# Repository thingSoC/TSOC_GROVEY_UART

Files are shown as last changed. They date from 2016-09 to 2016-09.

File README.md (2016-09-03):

# TSOC_GROVEY_UART

The thingSoC GROVEY_UART Base board incorporates a Cypress CY7C65215 Dual Channel USB Bridge, that supports UART, I2C, SPI, and JTAG interfaces in a thingSoC format.

The thingSoC GROVEY_UART Base board has two USB bridge channels, which can be programmed to be either UART, I2C, SPI, JTAG, or Capacitance Sensing (buttons/sliders) Human Input devices.

USB Bridge One (Port 1) and USB Bridge Two (Port 2) are both connected to Grove System compatible connectors, and USB Bridge One (Port 1) is also connected to the thingSoC standard UART channel.

Port1 can be used to program a target microprocessor, at the same time Port2 is used for another purpose (i.e. debug channel, USB to RS-485 bridge, etc).  

It's like having two (2) FTDI adapters in One!

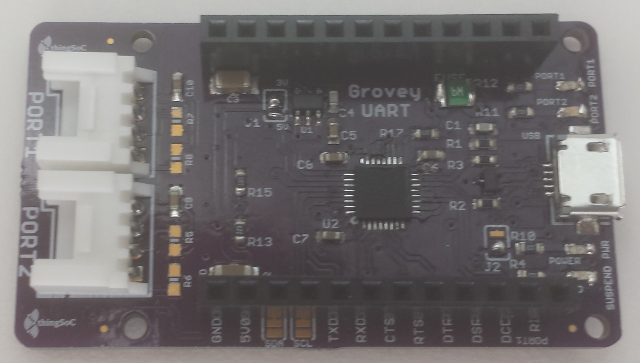
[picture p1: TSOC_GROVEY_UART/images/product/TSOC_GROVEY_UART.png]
thingSoC TSOC_GROVEY_UART
[ 
TSOC_GROVEY_UART](https://github.com/thingSoC/TSOC_GROVEY_UART)

---------------------------------------
## Use it as a Programming Dongle

---------------------------------------
## Use it as a Protocol Adapter

---------------------------------------
## TSOC_GROVEY_UART Model Images

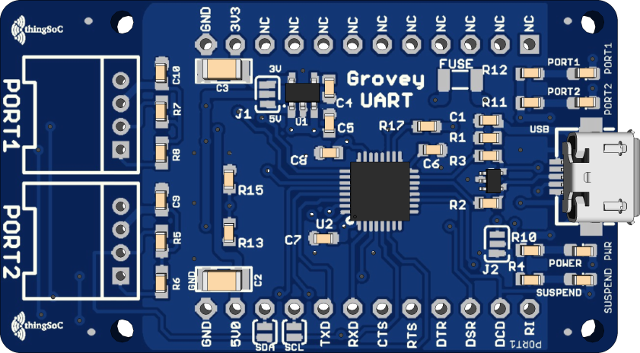
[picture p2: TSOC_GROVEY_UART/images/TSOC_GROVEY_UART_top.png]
thingSoC TSOC_GROVEY_UART
[ 
TSOC_GROVEY_UART](https://github.com/thingSoC/TSOC_GROVEY_UART)

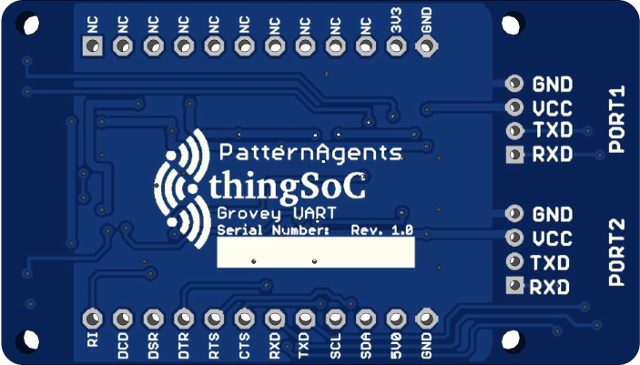
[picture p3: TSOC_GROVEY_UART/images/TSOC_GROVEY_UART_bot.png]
thingSoC TSOC_GROVEY_UART
[ 
TSOC_GROVEY_UART](https://github.com/thingSoC/TSOC_GROVEY_UART)

---------------------------------------

## TSOC_GROVEY_UART Status <a name="TSOC_GROVEY_UART_status"/>

Revision 1.0 - 09/02/2016

---------------------------------------

## TSOC_GROVEY_UART Documentation Index <a name="TSOC_GROVEY_UART_documentation_index"/>

[TSOC_GROVEY_UART Project](https://github.com/thingSoC/TSOC_GROVEY_UART/)

[TSOC_GROVEY_UART Hardware](https://github.com/thingSoC/TSOC_GROVEY_UART/tree/master/TSOC_GROVEY_UART/hardware)

---------------------------------------

## thingSoC Documentation Index <a name="thingSoC_documentation_index"/>

[thingSoC Organization Website](http://thingSoC.github.io)

[thingSoC FAQ - Frequently Asked Questions](http://thingsoc.github.io/support/faq.html)

---------------------------------------

[thingSoC 
*thingSoC*](http://thingsoc.github.io)

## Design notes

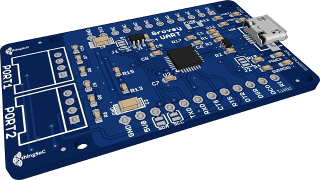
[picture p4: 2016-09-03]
TSOC_GROVEY_UART/images/TSOC_GROVEY_UART_model.png

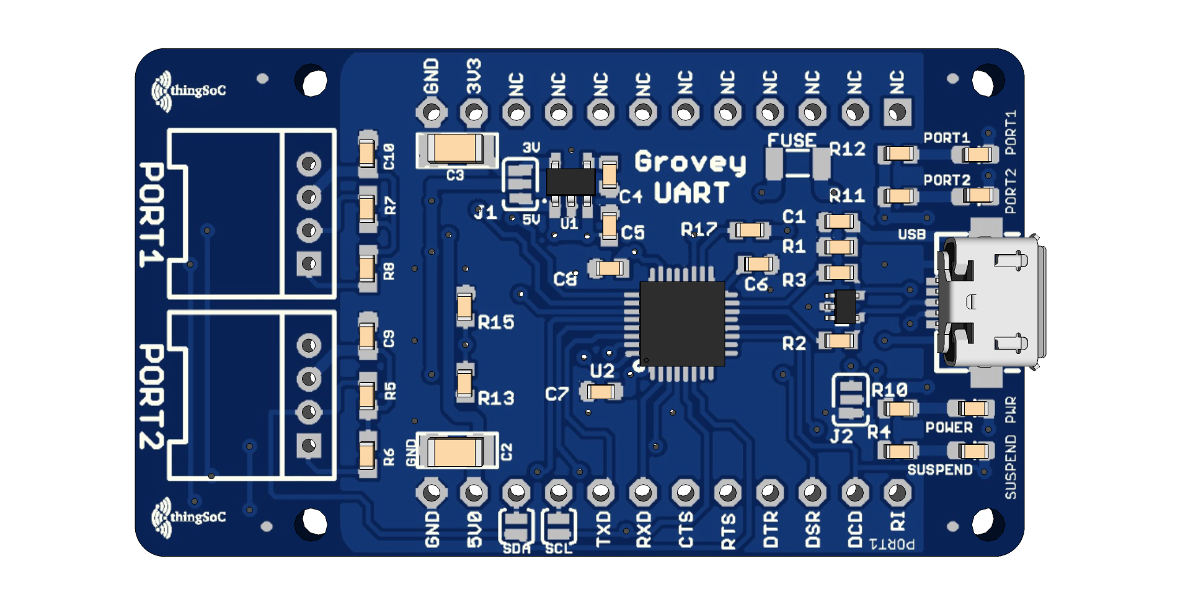
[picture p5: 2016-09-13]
TSOC_GROVEY_UART/images/TSOC_GROVEY_UART.png

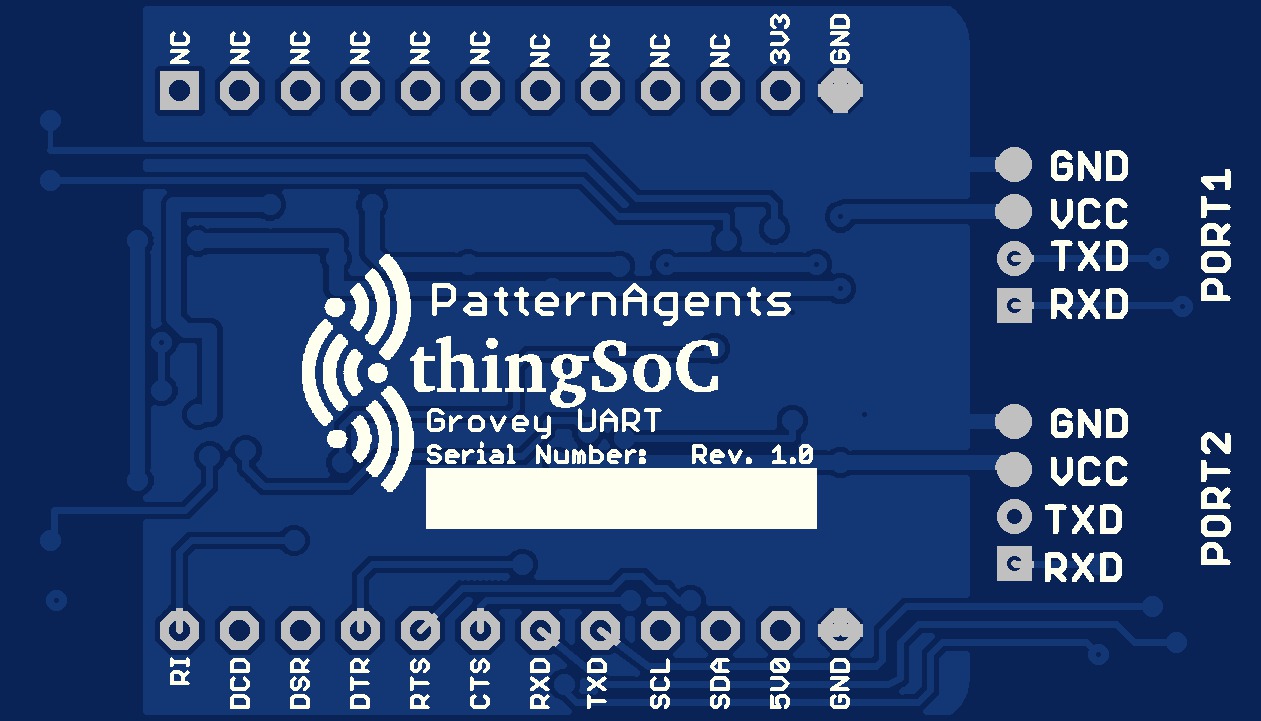
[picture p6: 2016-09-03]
TSOC_GROVEY_UART/eagleUp/eagleUp_TSOC_GROVEY_UART_board_bottom.jpg

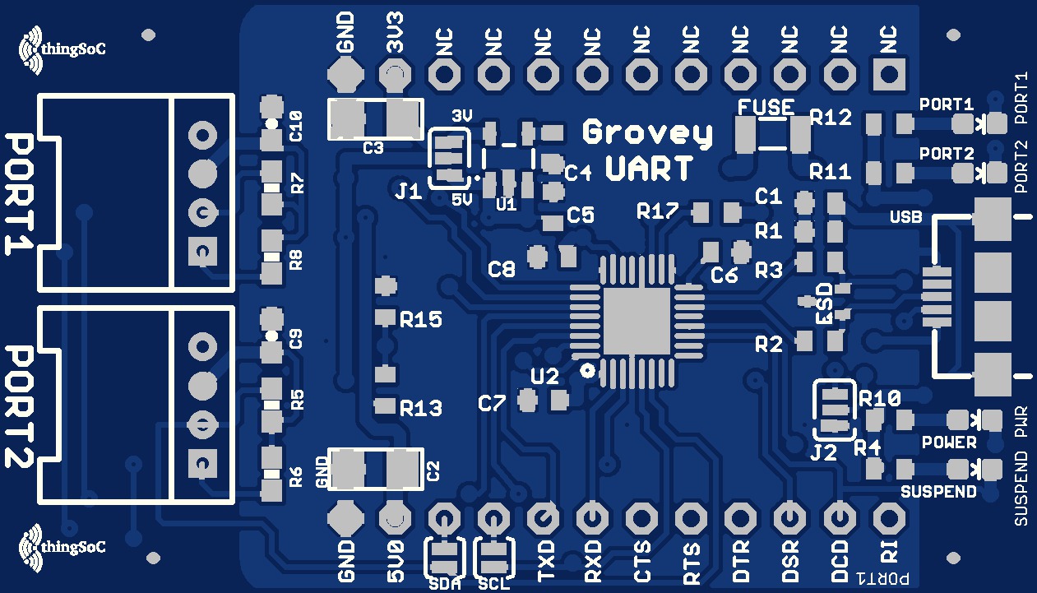
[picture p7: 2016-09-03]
TSOC_GROVEY_UART/eagleUp/eagleUp_TSOC_GROVEY_UART_board_top.jpg

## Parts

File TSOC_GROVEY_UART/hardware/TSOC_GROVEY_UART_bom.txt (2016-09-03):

Partlist exported from /data/customers/PatternAgents/eagle/TSOC_Modules/TSOC_GROVEY_UART/TSOC_GROVEY_UART/TSOC_GROVEY_UART.sch at 8/25/16 1:26 PM

Qty Value              Device                          Package                  Parts                  Description                                                                                                                                                                               
2                      JMP-2-NO                        JMP-2-NO                 SCL, SDA               Two Terminal Jumper - Normally Open                                                                                                                                                       
3   0.1uF              CAP-0603                        EIA-0603                 C5, C7, C8             Ceramic Capacitor SMD                                                                                                                                                                     
2   0.1uF              CAP0603-CAP                     0603-CAP                 C9, C10                Capacitor                                                                                                                                                                                 
1   1.0uF              CAP-0603                        EIA-0603                 C6                     Ceramic Capacitor SMD                                                                                                                                                                     
2   10K                RESISTOR-0603                   EIA-0603                 R15, R17                                                                                                                                                                                                         
4   1K                 RESISTOR-0603                   EIA-0603                 R4, R10, R11, R12                                                                                                                                                                                                
1   1M                 RESISTOR-0603                   EIA-0603                 R1                                                                                                                                                                                                               
2   22                 RESISTOR-0603                   EIA-0603                 R2, R3                                                                                                                                                                                                           
1   22K                RESISTOR-0603                   EIA-0603                 R13                                                                                                                                                                                                              
2   22uF               CAP-1206                        EIA-1206                 C2, C3                 Ceramic Capacitor SMD                                                                                                                                                                     
2   470pF              CAP-0603                        EIA-0603                 C1, C4                 Ceramic Capacitor SMD                                                                                                                                                                     
2   4P-2.0-90D         GROVE-CONNECTOR-DIP-90D(4P-2.0) HW4-2.0-90D              UART1, UART2           320110034                                                                                                                                                                                 
1   500mA-PTC          PTCSMD                          PTC-1206                 FUSE                   Resettable Fuse PTC                                                                                                                                                                       
1   BLUE               LED0603                         LED-0603                 PORT2                  LEDs                                                                                                                                                                                      
1   CY7C65215-32-PROTO CY7C65215-32-PROTO              QFN32-PROTO              U2                     Cypress EZ-USB ® CY7C65215-32QFN DUAL CHANNEL USB TO UART/SPI/IC Bridge                                                                                                                   
4   DNP                RESISTOR0603-RES                0603-RES                 R5, R6, R7, R8         Resistor                                                                                                                                                                                  
4   FIDUCIALUFIDUCIAL  FIDUCIALUFIDUCIAL               MICRO-FIDUCIAL           FID1, FID2, FID3, FID4 Fiducial Alignment Points                                                                                                                                                                 
1   GRN                LED0603                         LED-0603                 POWER                  LEDs                                                                                                                                                                                      
2   JMP-3-1_2          JMP-3-1_2                       JMP-3-1_2                J1, J2                 Three Terminal Jumper - 1 & 2 Connected                                                                                                                                                   
1   MIC5219 3.3V       V_REG_MIC52193.3V               SOT23-5                  U1                     V_REG MIC5219                                                                                                                                                                             
1   RED                LED0603                         LED-0603                 SUSPEND                LEDs                                                                                                                                                                                      
1   SP1001-02JTG       SP1001-02JTG                    SC70-3                   ESD                    Littelfuse SP1001-02JTG TVS Diode Array 8pf 15kV Source: 
1   USB_AB             USB_AB                          USB-AB-MICRO-SMD         USB                    This is a USB AB connector that is compatible with USB OTG.                                                                            
1   YELLOW             LED0603                         LED-0603                 PORT1                  LEDs

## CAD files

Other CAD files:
TSOC_GROVEY_UART/eagleUp/TSOC_GROVEY_UART.skp

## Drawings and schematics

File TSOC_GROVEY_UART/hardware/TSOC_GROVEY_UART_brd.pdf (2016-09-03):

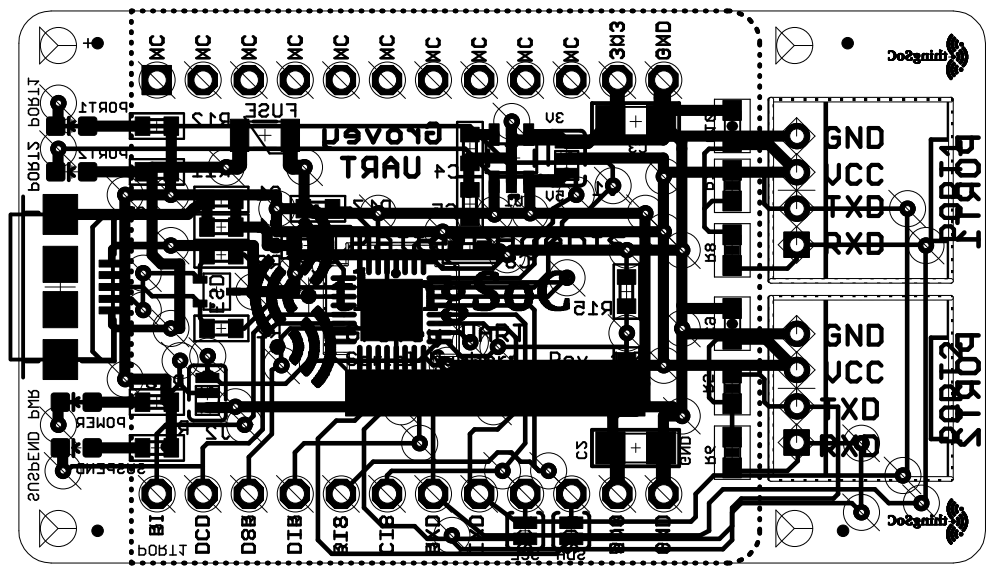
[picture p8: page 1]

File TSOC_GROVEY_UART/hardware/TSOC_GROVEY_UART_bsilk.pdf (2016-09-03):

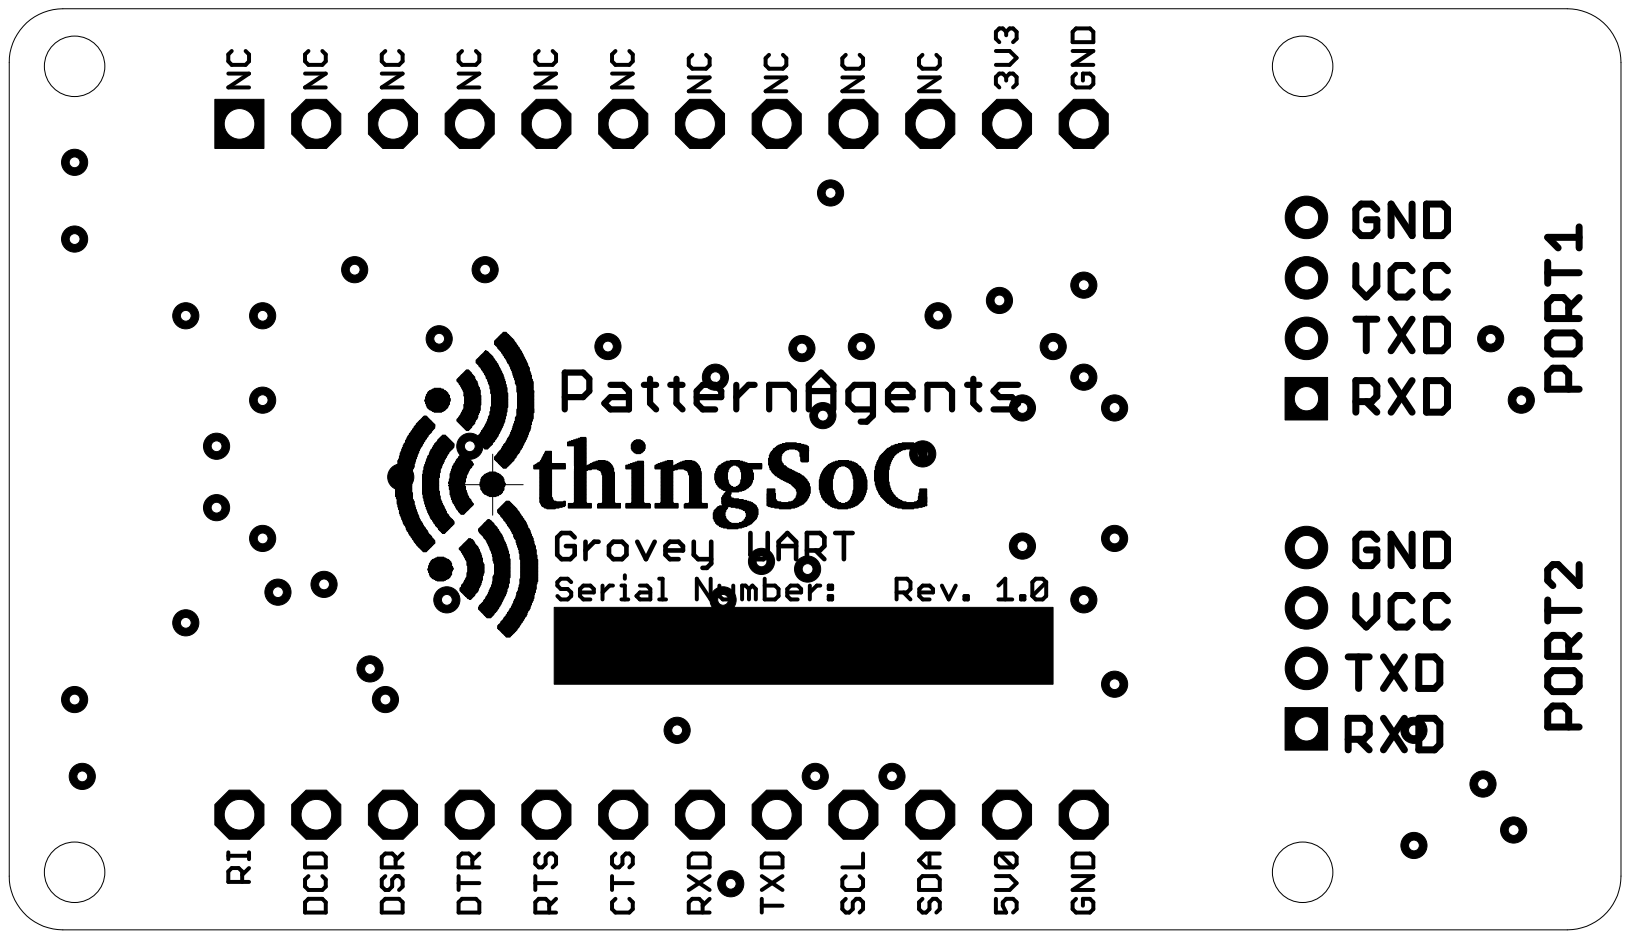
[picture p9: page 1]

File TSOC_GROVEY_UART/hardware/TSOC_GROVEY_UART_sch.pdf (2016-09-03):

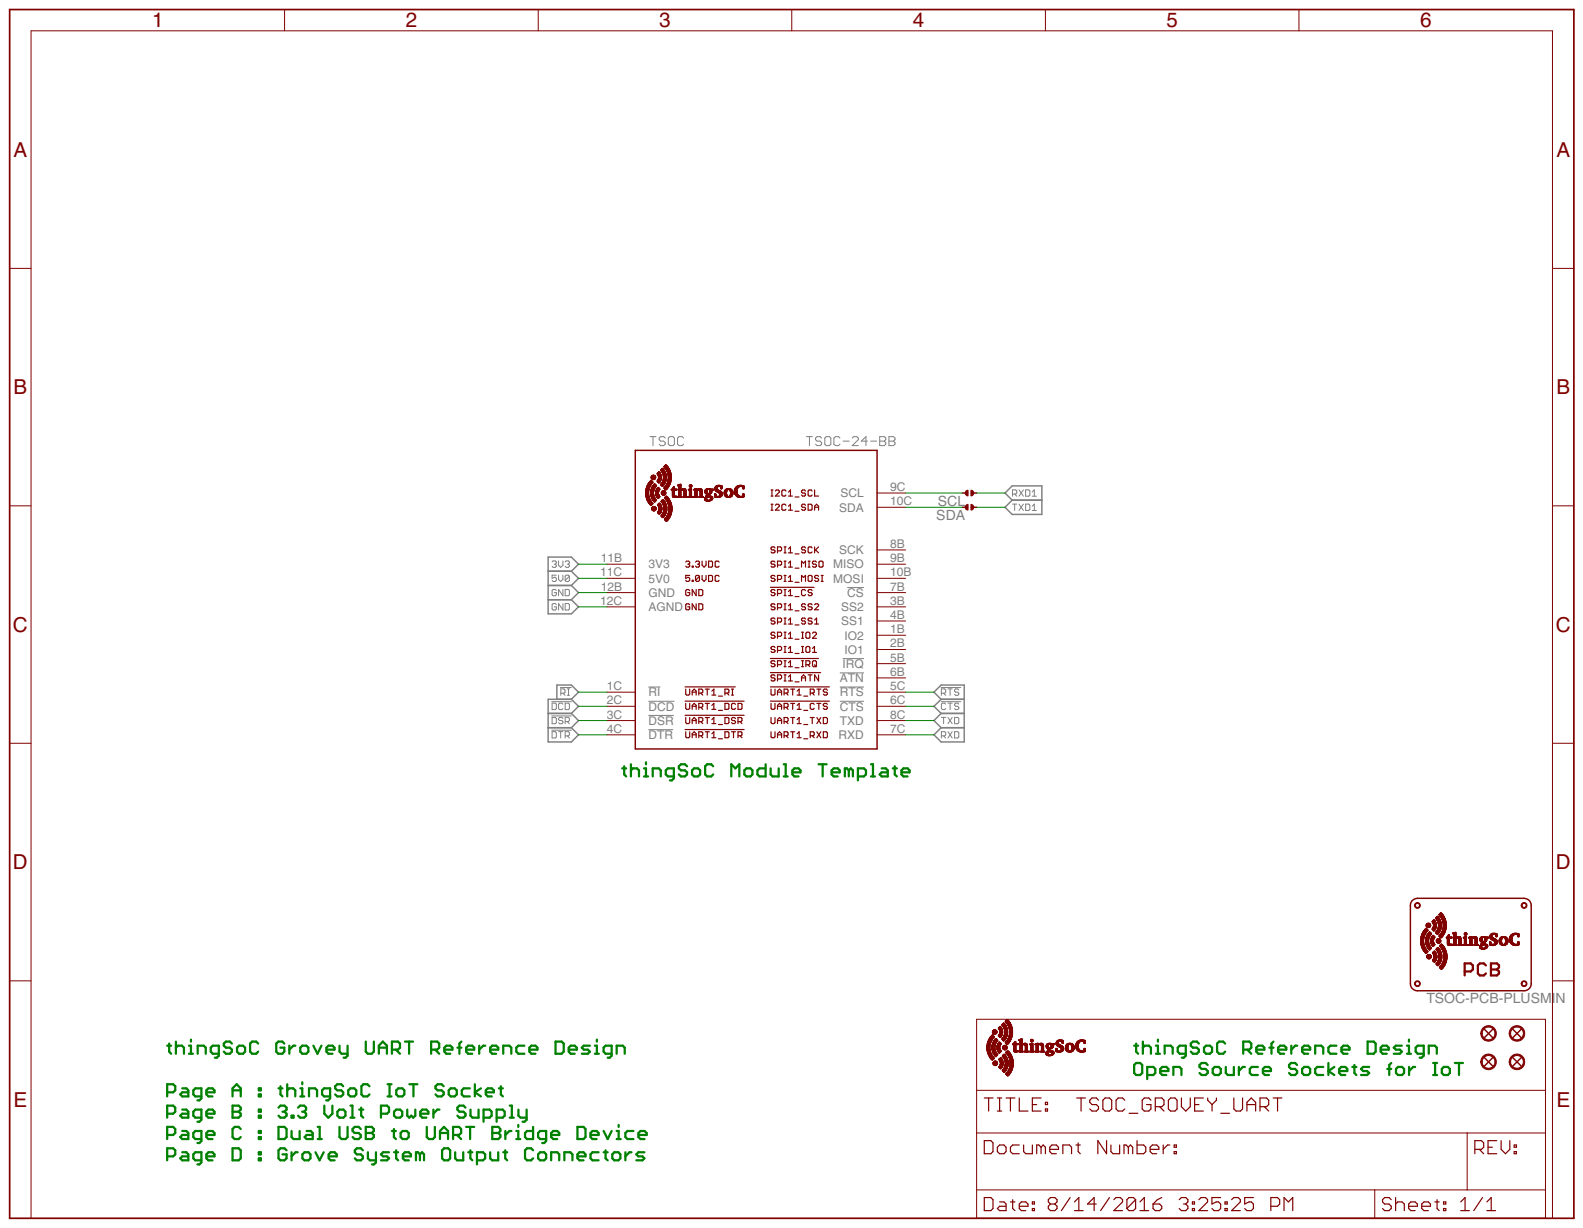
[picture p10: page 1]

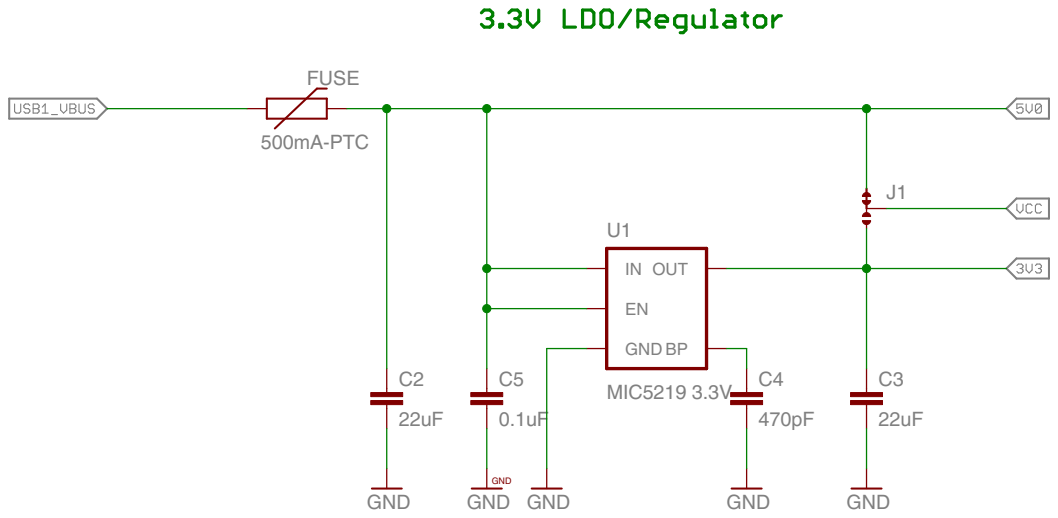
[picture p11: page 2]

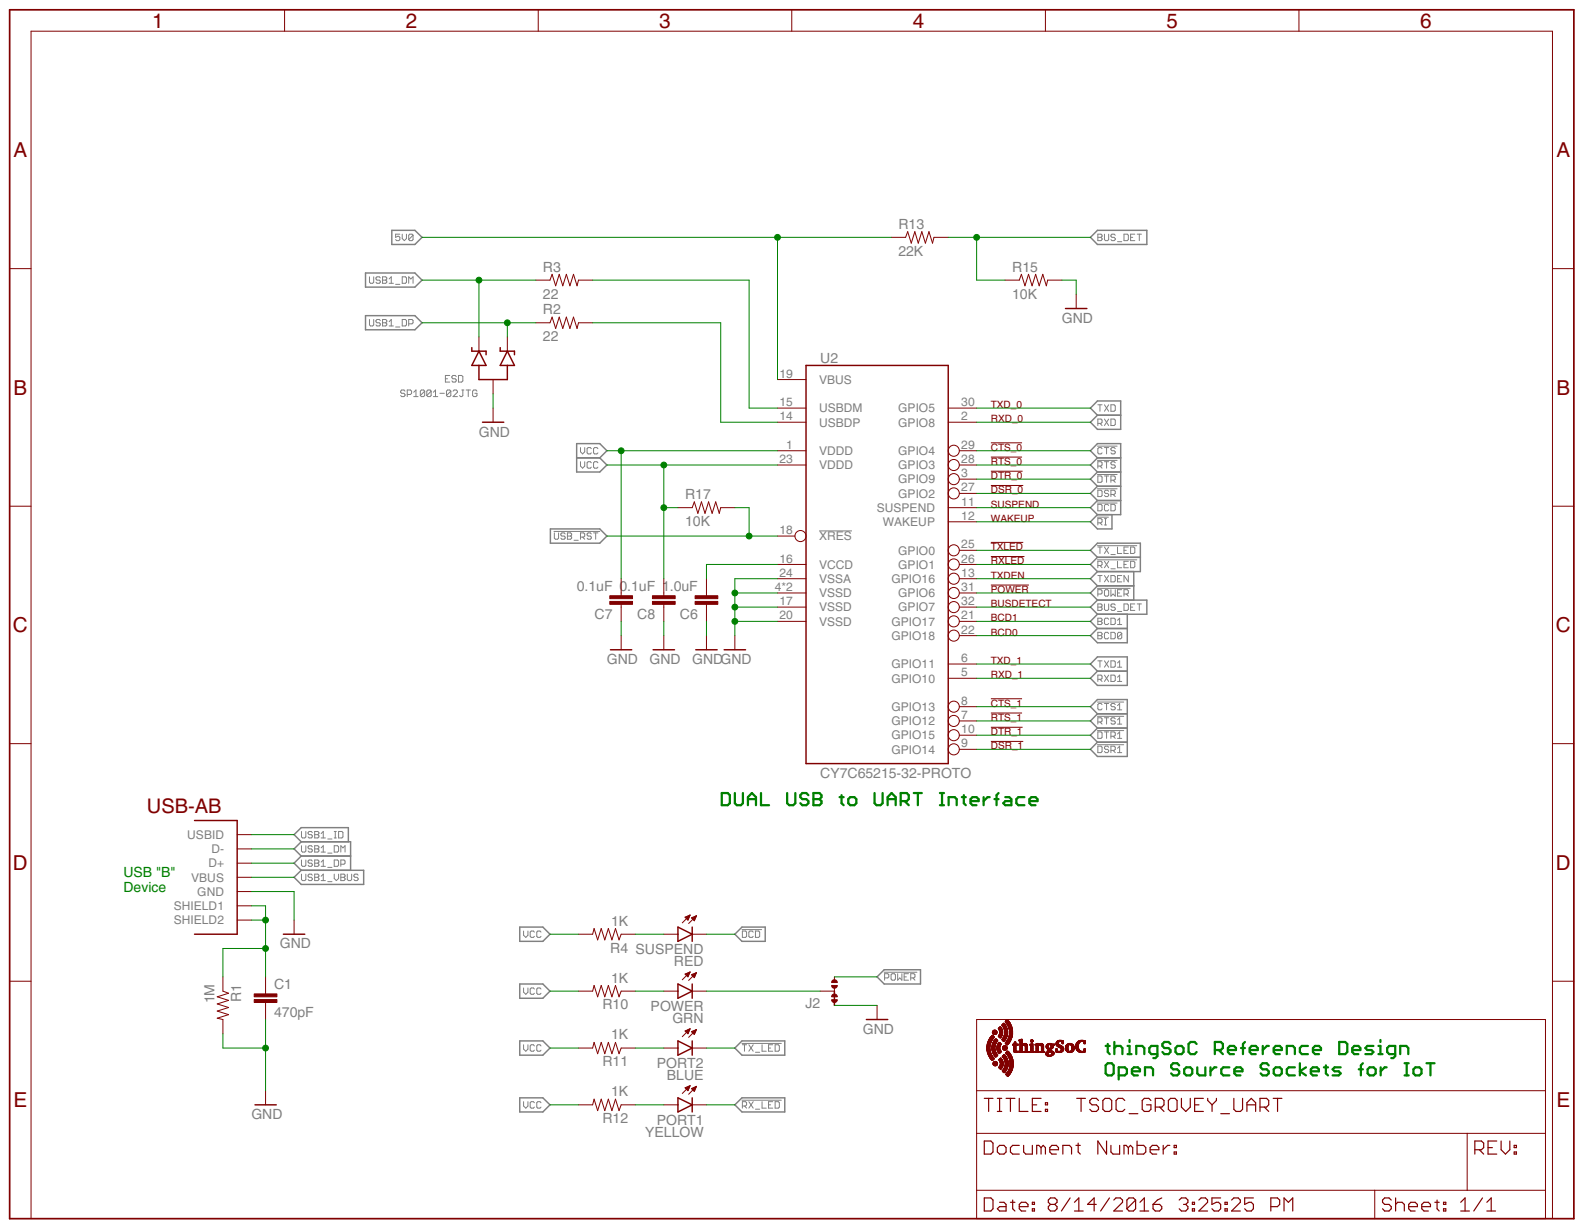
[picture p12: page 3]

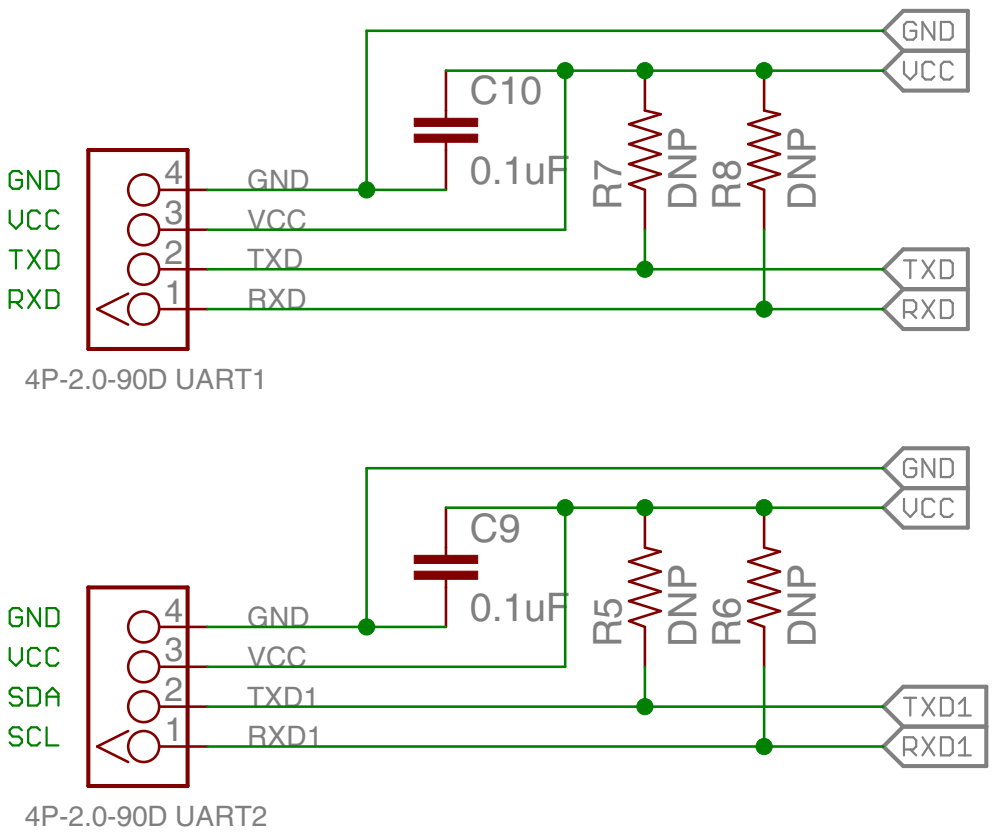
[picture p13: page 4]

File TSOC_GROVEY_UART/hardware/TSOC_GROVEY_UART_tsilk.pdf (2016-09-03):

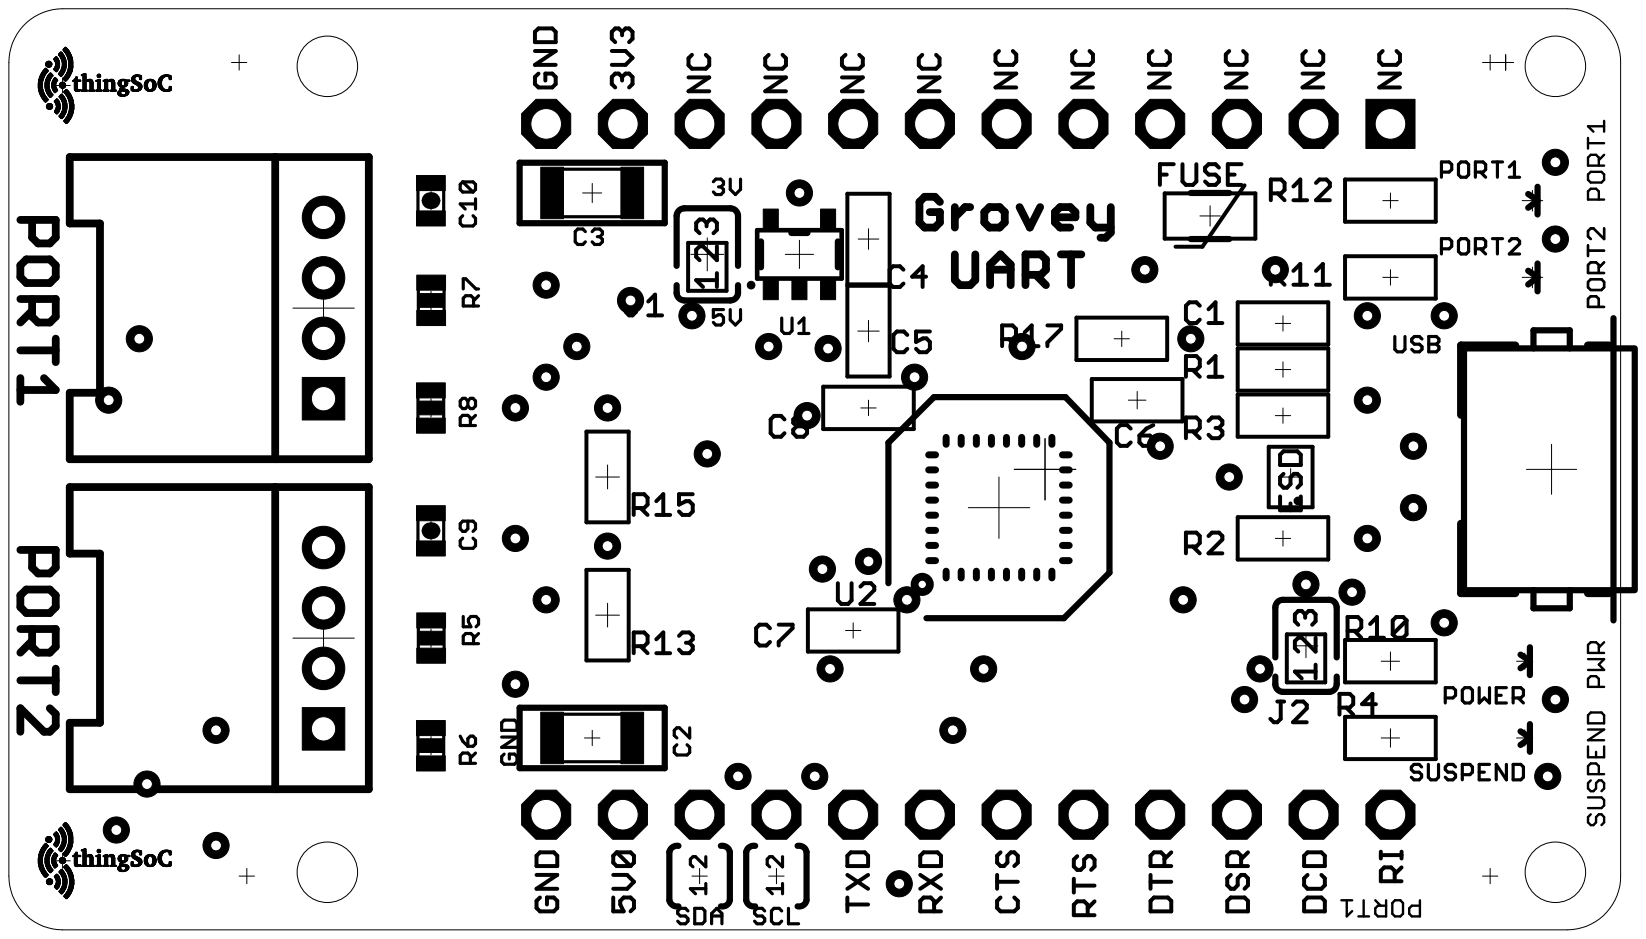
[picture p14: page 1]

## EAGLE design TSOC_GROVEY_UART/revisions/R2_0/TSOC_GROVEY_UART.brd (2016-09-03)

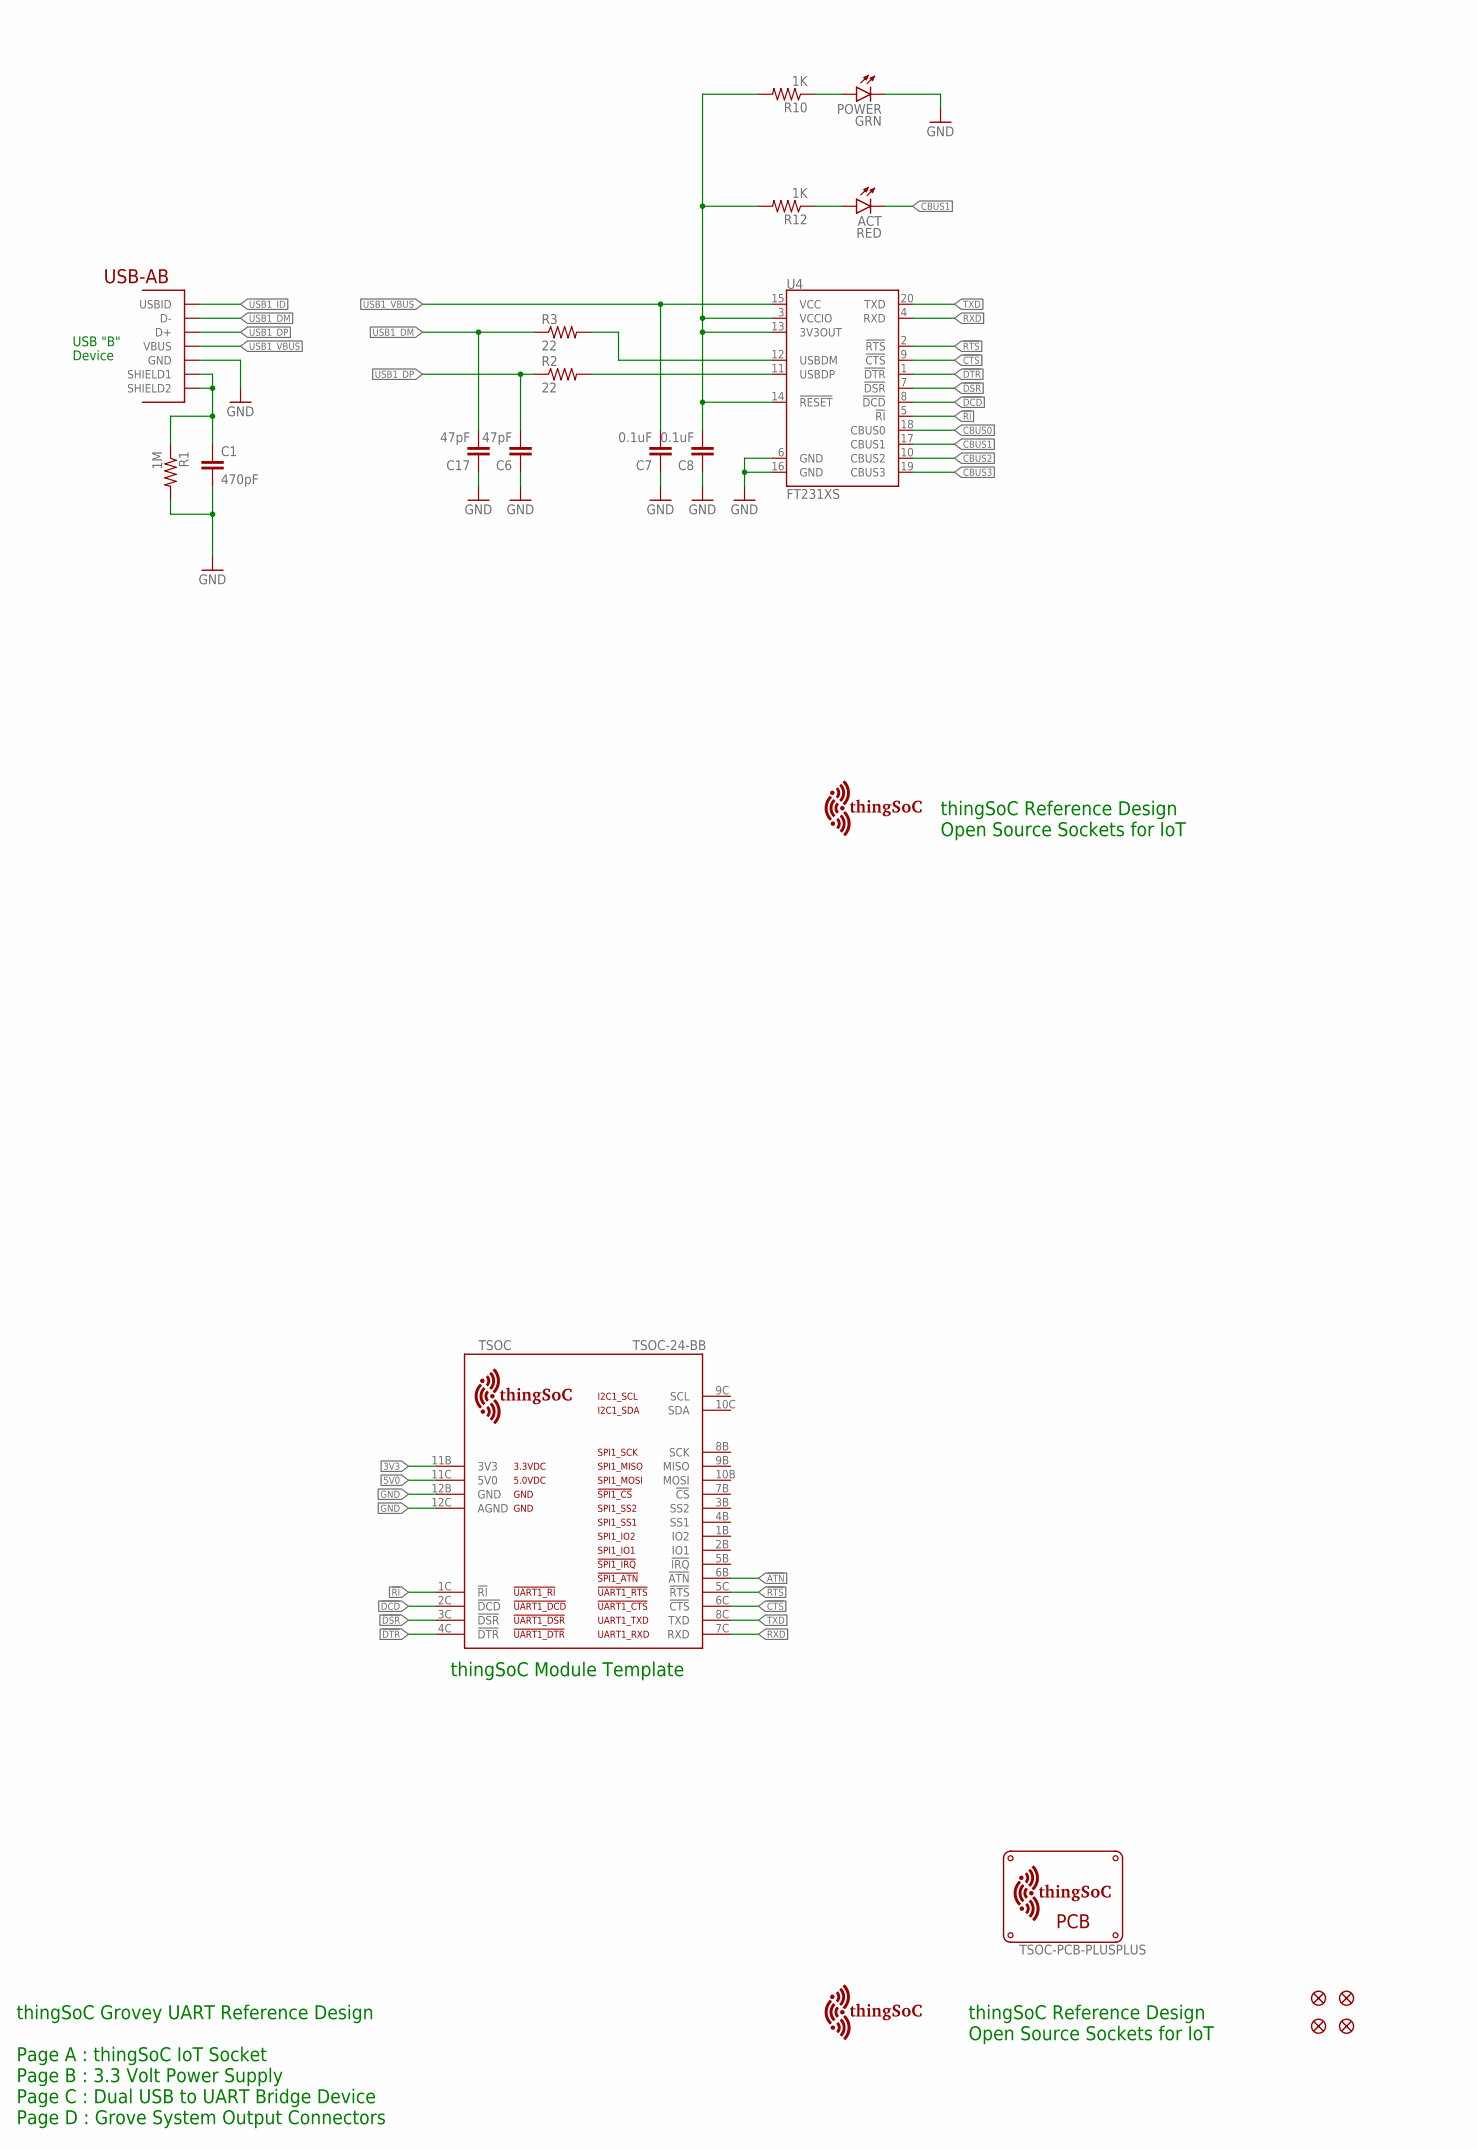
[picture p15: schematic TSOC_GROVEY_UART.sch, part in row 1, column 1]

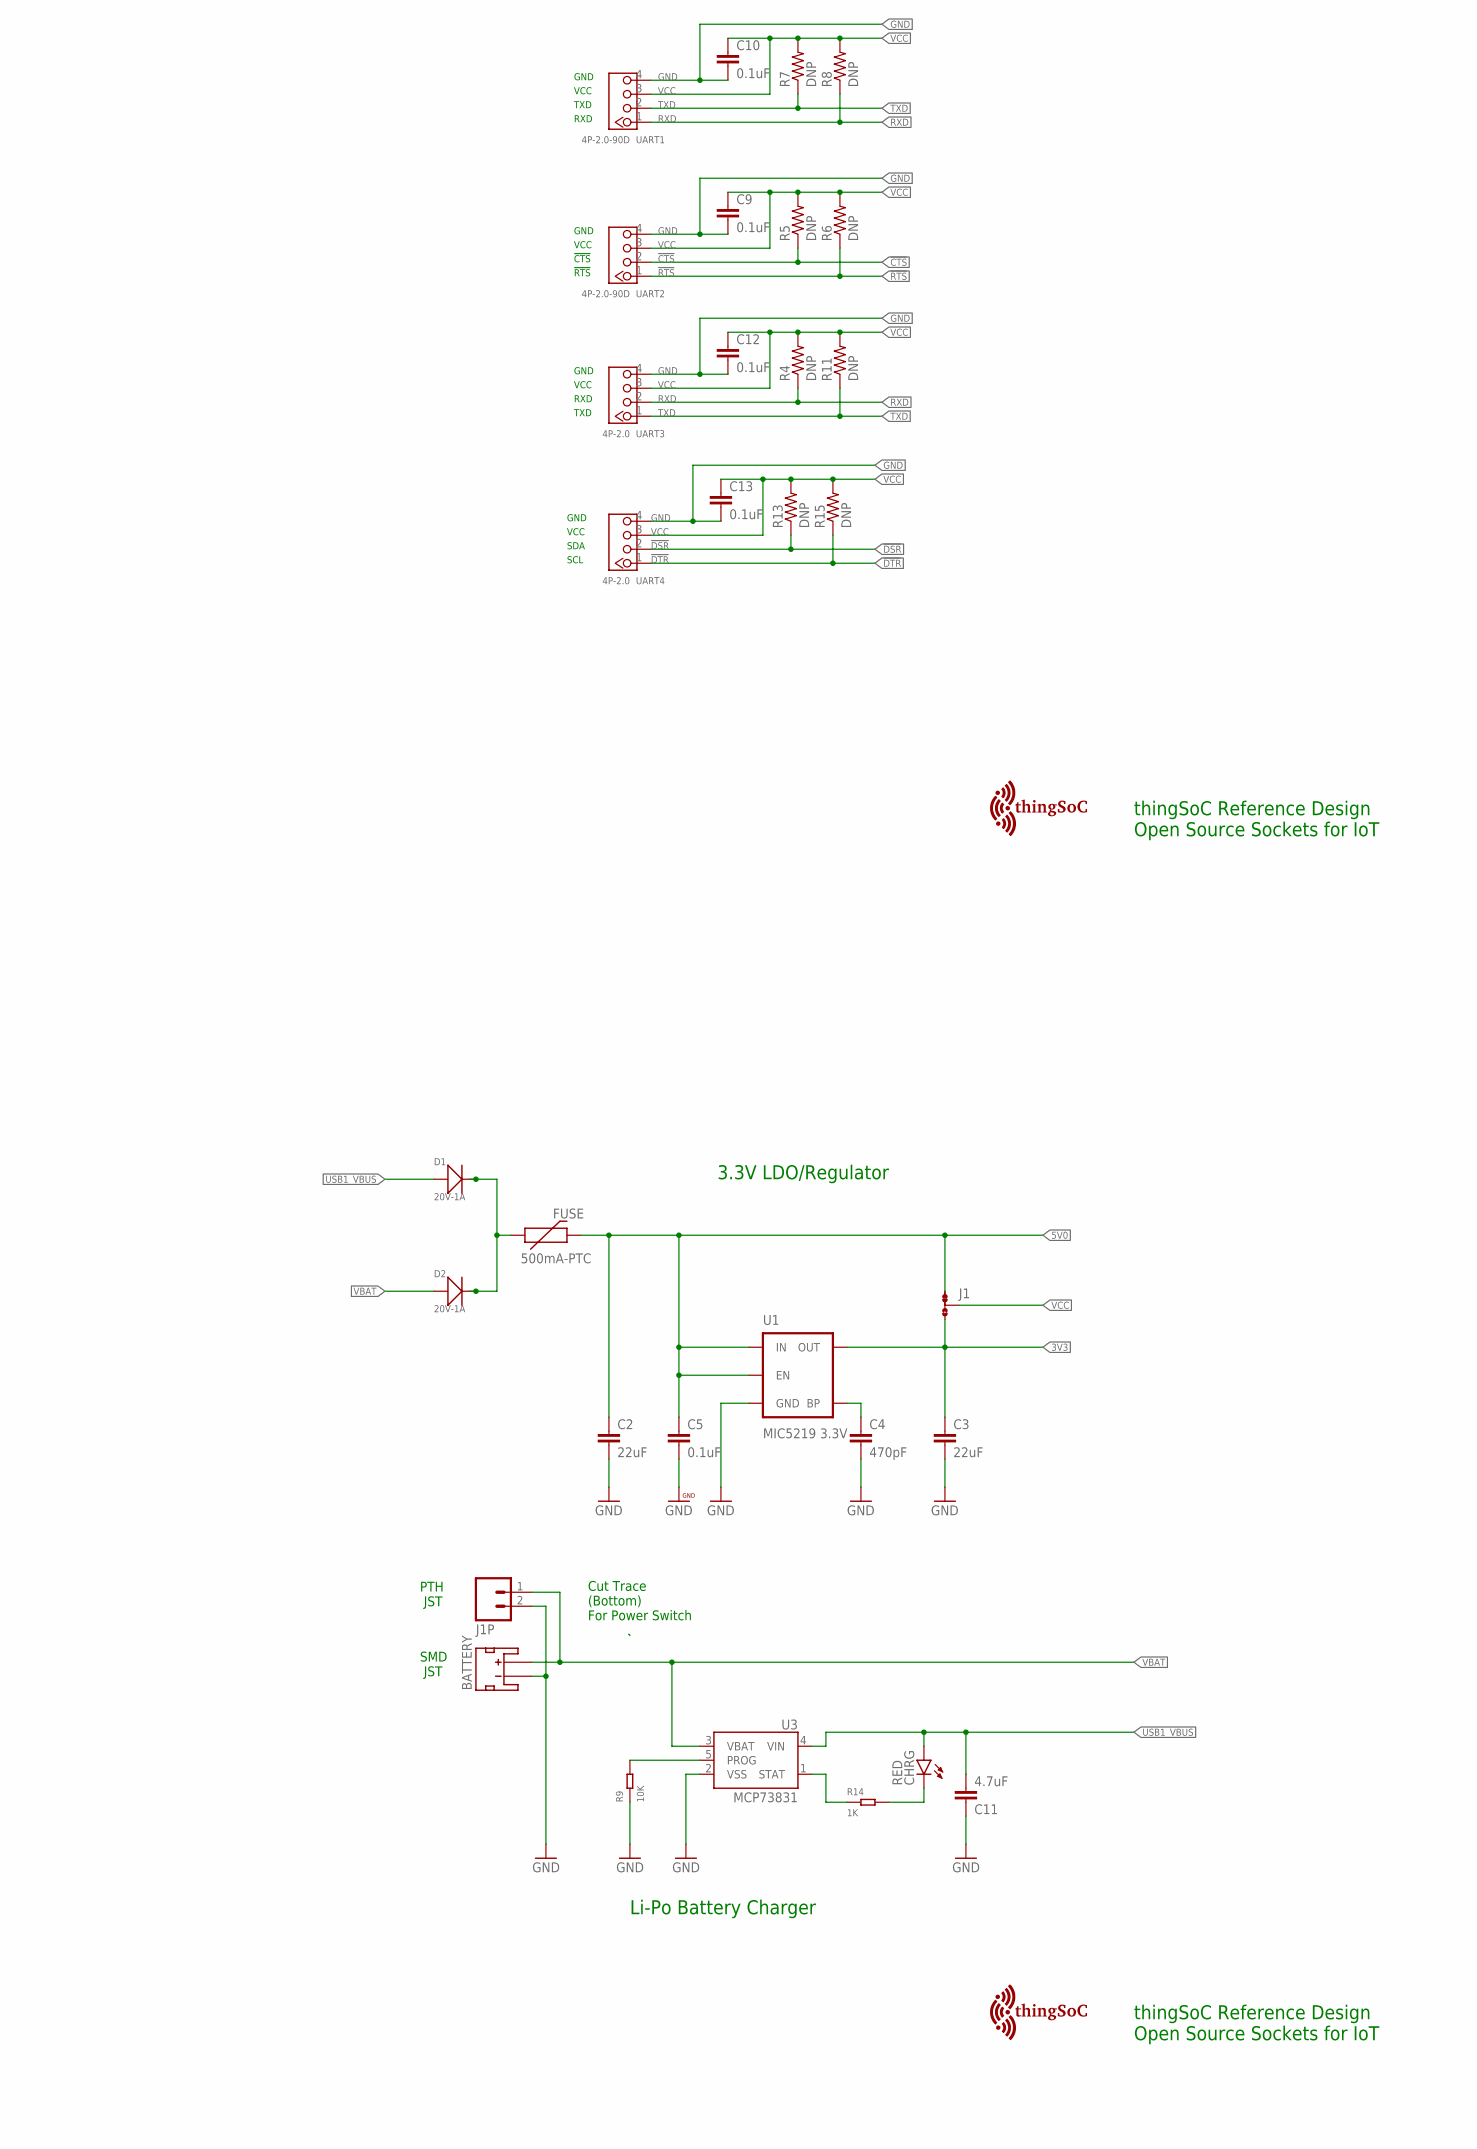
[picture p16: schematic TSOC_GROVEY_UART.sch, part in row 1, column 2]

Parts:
ACT: RED; LED-0603
BATTERY: JST_2MM_MALE; JST-2-SMD
C1, C4: 470pF; EIA-0603
C2, C3: 22uF; EIA-1206
C5, C7, C8: 0.1uF; EIA-0603
C6, C17: 47pF; EIA-0603
C9, C10, C12, C13: 0.1uF; 0603-CAP
C11: 4.7uF; 0402-CAP
CHRG: RED; LED-0603
D1, D2: 20V-1A; SOD-123
FID1, FID2, FID3, FID4: FIDUCIALUFIDUCIAL; MICRO-FIDUCIAL
FUSE: 500mA-PTC; PTC-1206
J1: JMP-3-1_2
J1P: M02-JST-2-PTH-NO_SILK; JST-2-PTH-NS
POWER: GRN; LED-0603
R1: 1M; EIA-0603
R2, R3: 22; EIA-0603
R4, R5, R6, R7, R8, R11, R13, R15: DNP; 0603-RES
R9: 10K; R0603
R10, R12: 1K; EIA-0603
R14: 1K; R0603
TSOC: TSOC-24-BB; TSOC-BB-S24
U1: MIC5219 3.3V; SOT23-5
U3: MCP73831; SOT23-5
U4: FT231XS; SSOP20_L
U$3: TSOC-LOGO-LRG
U$4, U$5, U$6: TSOC-LOGO; TSOC-LOGO-BLANK
U$8: TSOC-PCB-PLUSPLUS; TSOC-BB-BRD-PLUS-PLUS-DIM
UART1, UART2: 4P-2.0-90D; HW4-2.0-90D
UART3, UART4: 4P-2.0; HW4-2.0
USB: USB_AB; USB-AB-MICRO-SMD

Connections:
3V3: C3.1, J1.3, TSOC.11B (3V3), U1.5 (OUT)
3V3U: C8.2, R10.2, R12.2, U4.3 (VCCIO), U4.13 (3V3OUT), U4.14 (!RESET)
5V0: C2.1, C5.1, FUSE.2, J1.1, TSOC.11C (5V0), U1.1 (IN), U1.3 (EN)
!ATN: TSOC.6B (!ATN)
!CTS: R5.1, TSOC.6C (!CTS), U4.9 (!CTS), UART2.2
!DCD: TSOC.2C (!DCD), U4.8 (!DCD)
!DSR: R13.1, TSOC.3C (!DSR), U4.7 (!DSR), UART4.2
!DTR: R15.1, TSOC.4C (!DTR), U4.1 (!DTR), UART4.1
!RI: TSOC.1C (!RI), U4.5 (!RI)
!RTS: R6.1, TSOC.5C (!RTS), U4.2 (!RTS), UART2.1
BYPASS1: C4.1, U1.4 (BP)
CBUS0: U4.18 (CBUS0)
CBUS1: ACT.C, U4.17 (CBUS1)
CBUS2: U4.10 (CBUS2)
CBUS3: U4.19 (CBUS3)
CLED: CHRG.C, R14.2
CSTAT: R14.1, U3.1 (STAT)
GND: BATTERY.1 (-), C1.2, C2.2, C3.2, C4.2, C5.2, C6.1, C7.1, C8.1, C9.2, C10.2, C11.1, C12.2, C13.2, C17.1, J1P.2, POWER.C, R1.2, R9.1, TSOC.12B (GND), TSOC.12C (AGND), U1.2 (GND), U3.2 (VSS), U4.6 (GND), U4.16 (GND), UART1.4, UART2.4, UART3.4, UART4.4, USB.GND
GRN: POWER.A, R10.1
unnamed: D1.-, D2.-, FUSE.1
RXD: R4.1, R8.1, TSOC.7C (RXD), U4.4 (RXD), UART1.1, UART3.2
TXD: R7.1, R11.1, TSOC.8C (TXD), U4.20 (TXD), UART1.2, UART3.1
USB1_DM: C17.2, R3.1, USB.D-
USB1_DP: C6.2, R2.1, USB.D+
USB1_ID: USB.ID (USBID)
USB1_M: R3.2, U4.12 (USBDM)
USB1_P: R2.2, U4.11 (USBDP)
USB1_SHIELD: C1.1, R1.1, USB.SHIELD1, USB.SHIELD2
USB1_VBUS: C7.2, C11.2, CHRG.A, D1.+, U3.4 (VIN), U4.15 (VCC), USB.VBUS
VBAT: BATTERY.2 (+), D2.+, J1P.1, U3.3 (VBAT)
VB_PROG: R9.2, U3.5 (PROG)
VCC: C9.1, C10.1, C12.1, C13.1, J1.2, R4.2, R5.2, R6.2, R7.2, R8.2, R11.2, R13.2, R15.2, UART1.3, UART2.3, UART3.3, UART4.3
YEL: ACT.A, R12.1

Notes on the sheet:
thingSoC Reference Design Open Source Sockets for IoT
USB "B"
Device
thingSoC Grovey UART Reference Design Page A : thingSoC IoT Socket Page B : 3.3 Volt Power Supply Page C : Dual USB to UART Bridge Device Page D : Grove System Output Connectors
thingSoC Module Template
3.3V LDO/Regulator
GND
VCC
RXD
TXD
!CTS
!RTS
Li-Po Battery Charger
Cut Trace (Bottom) For Power Switch
SMD JST
PTH JST
SDA
SCL

Board: 2 copper layers, 58 parts (2 on the bottom side), 28 nets, no tracks yet.

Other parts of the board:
U$1, U$7: TSOC-LOGO-SMALL; TSOC-LOGO-SML

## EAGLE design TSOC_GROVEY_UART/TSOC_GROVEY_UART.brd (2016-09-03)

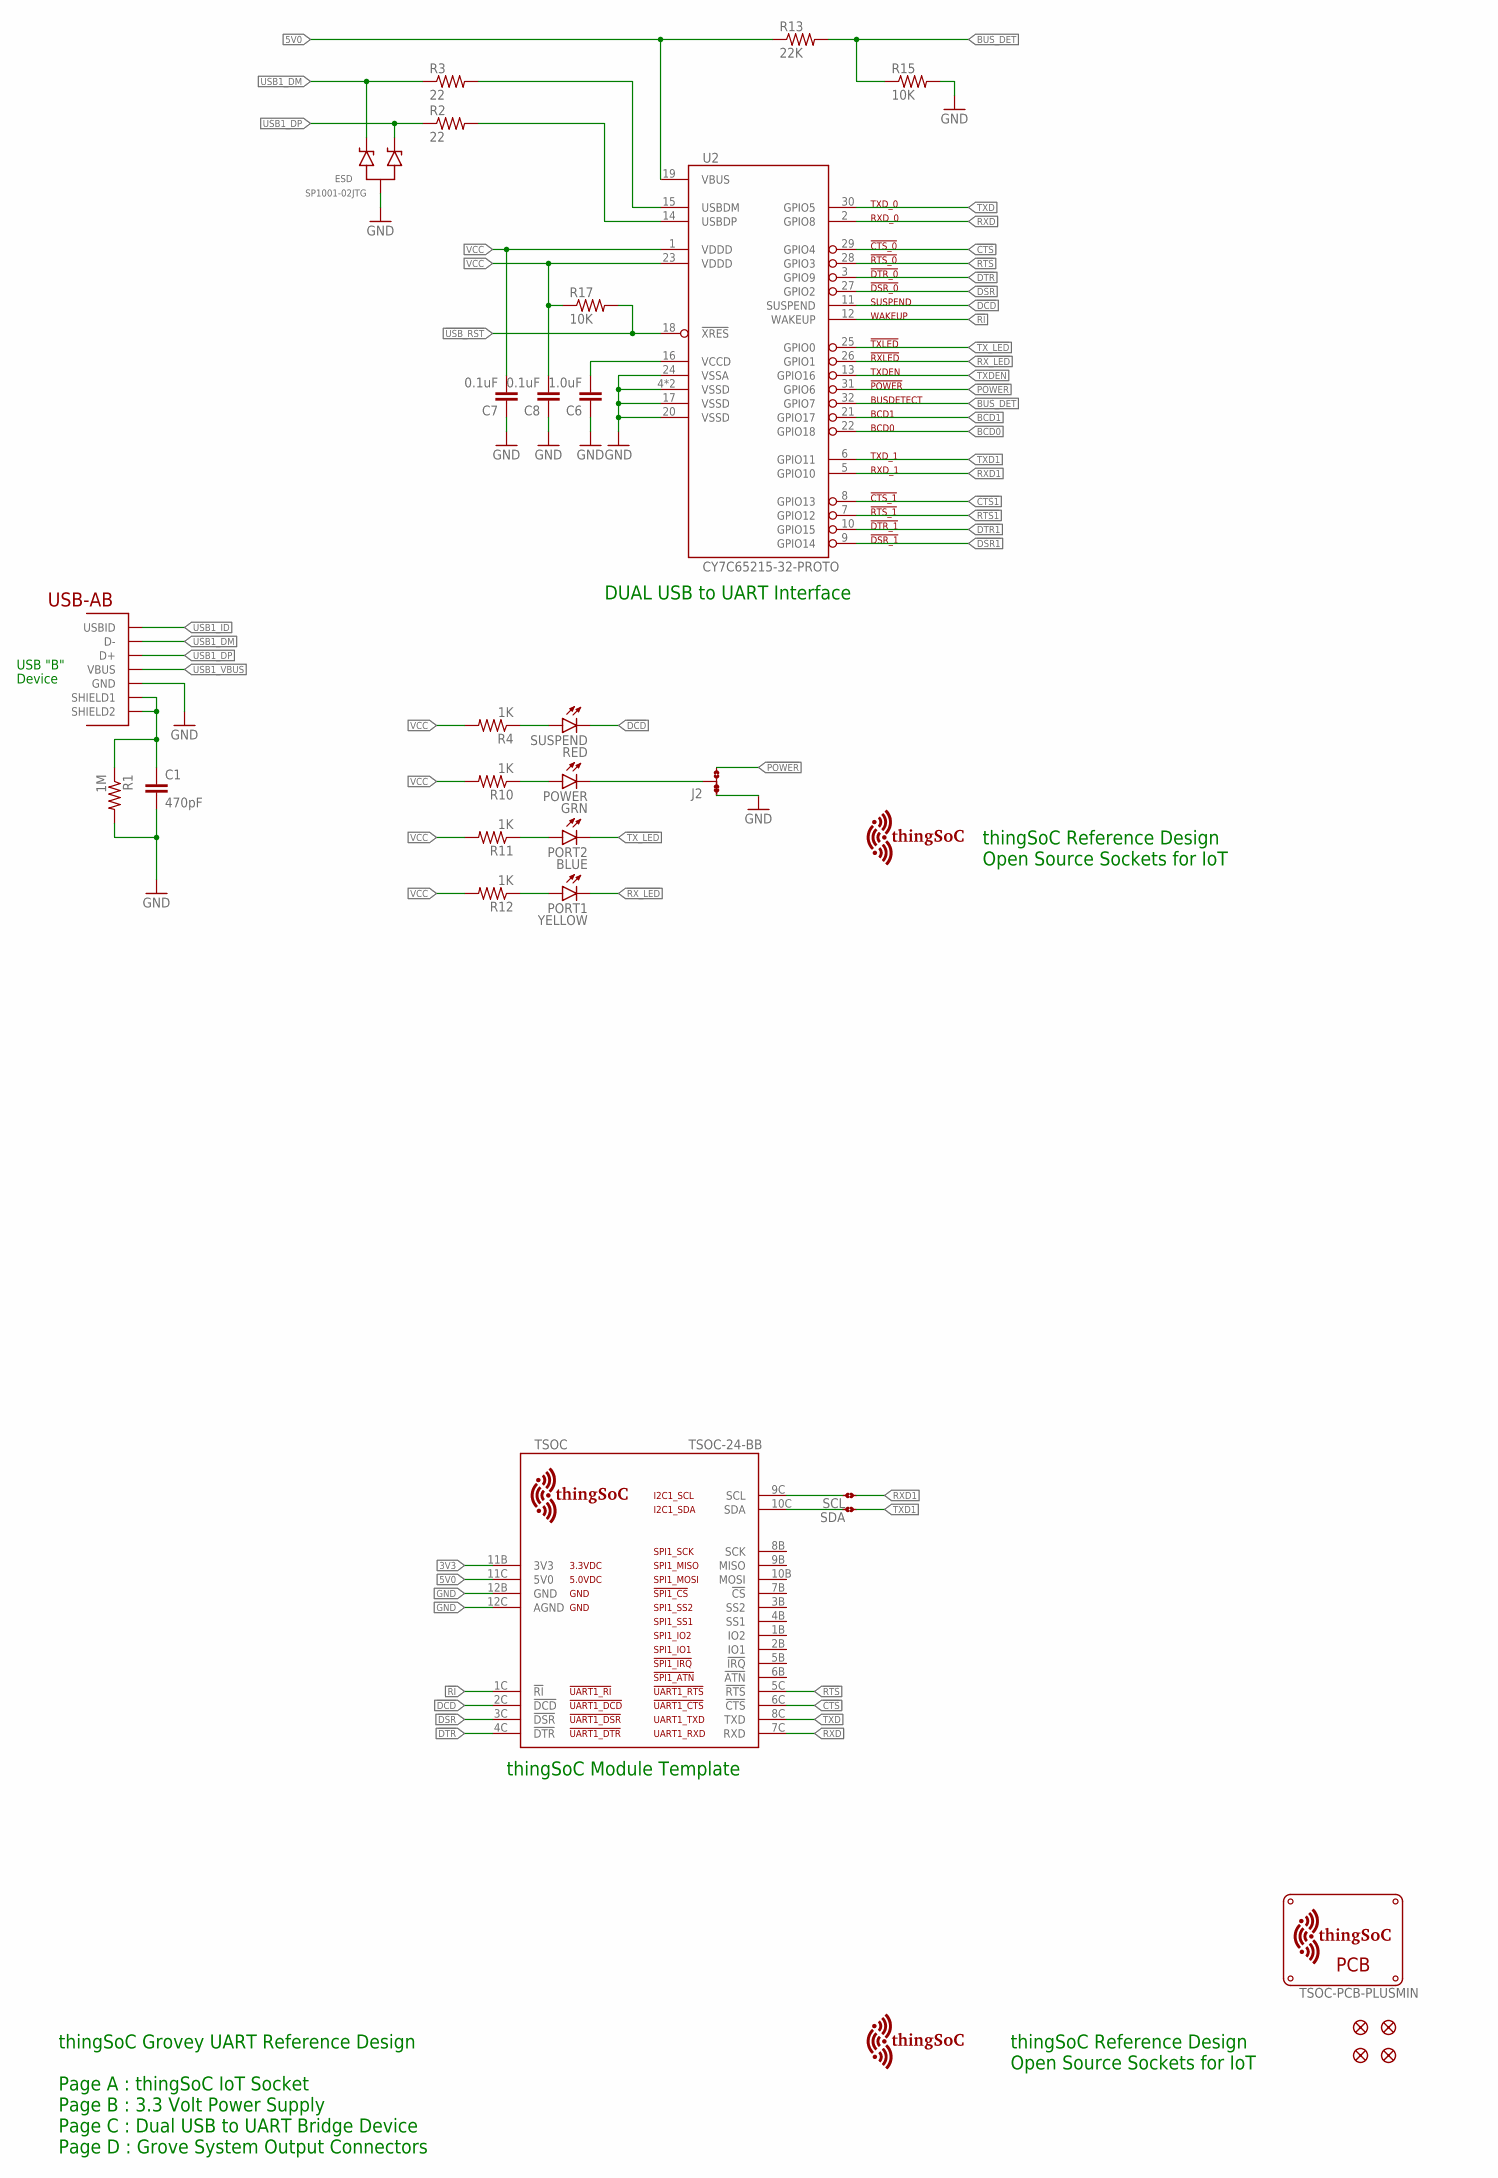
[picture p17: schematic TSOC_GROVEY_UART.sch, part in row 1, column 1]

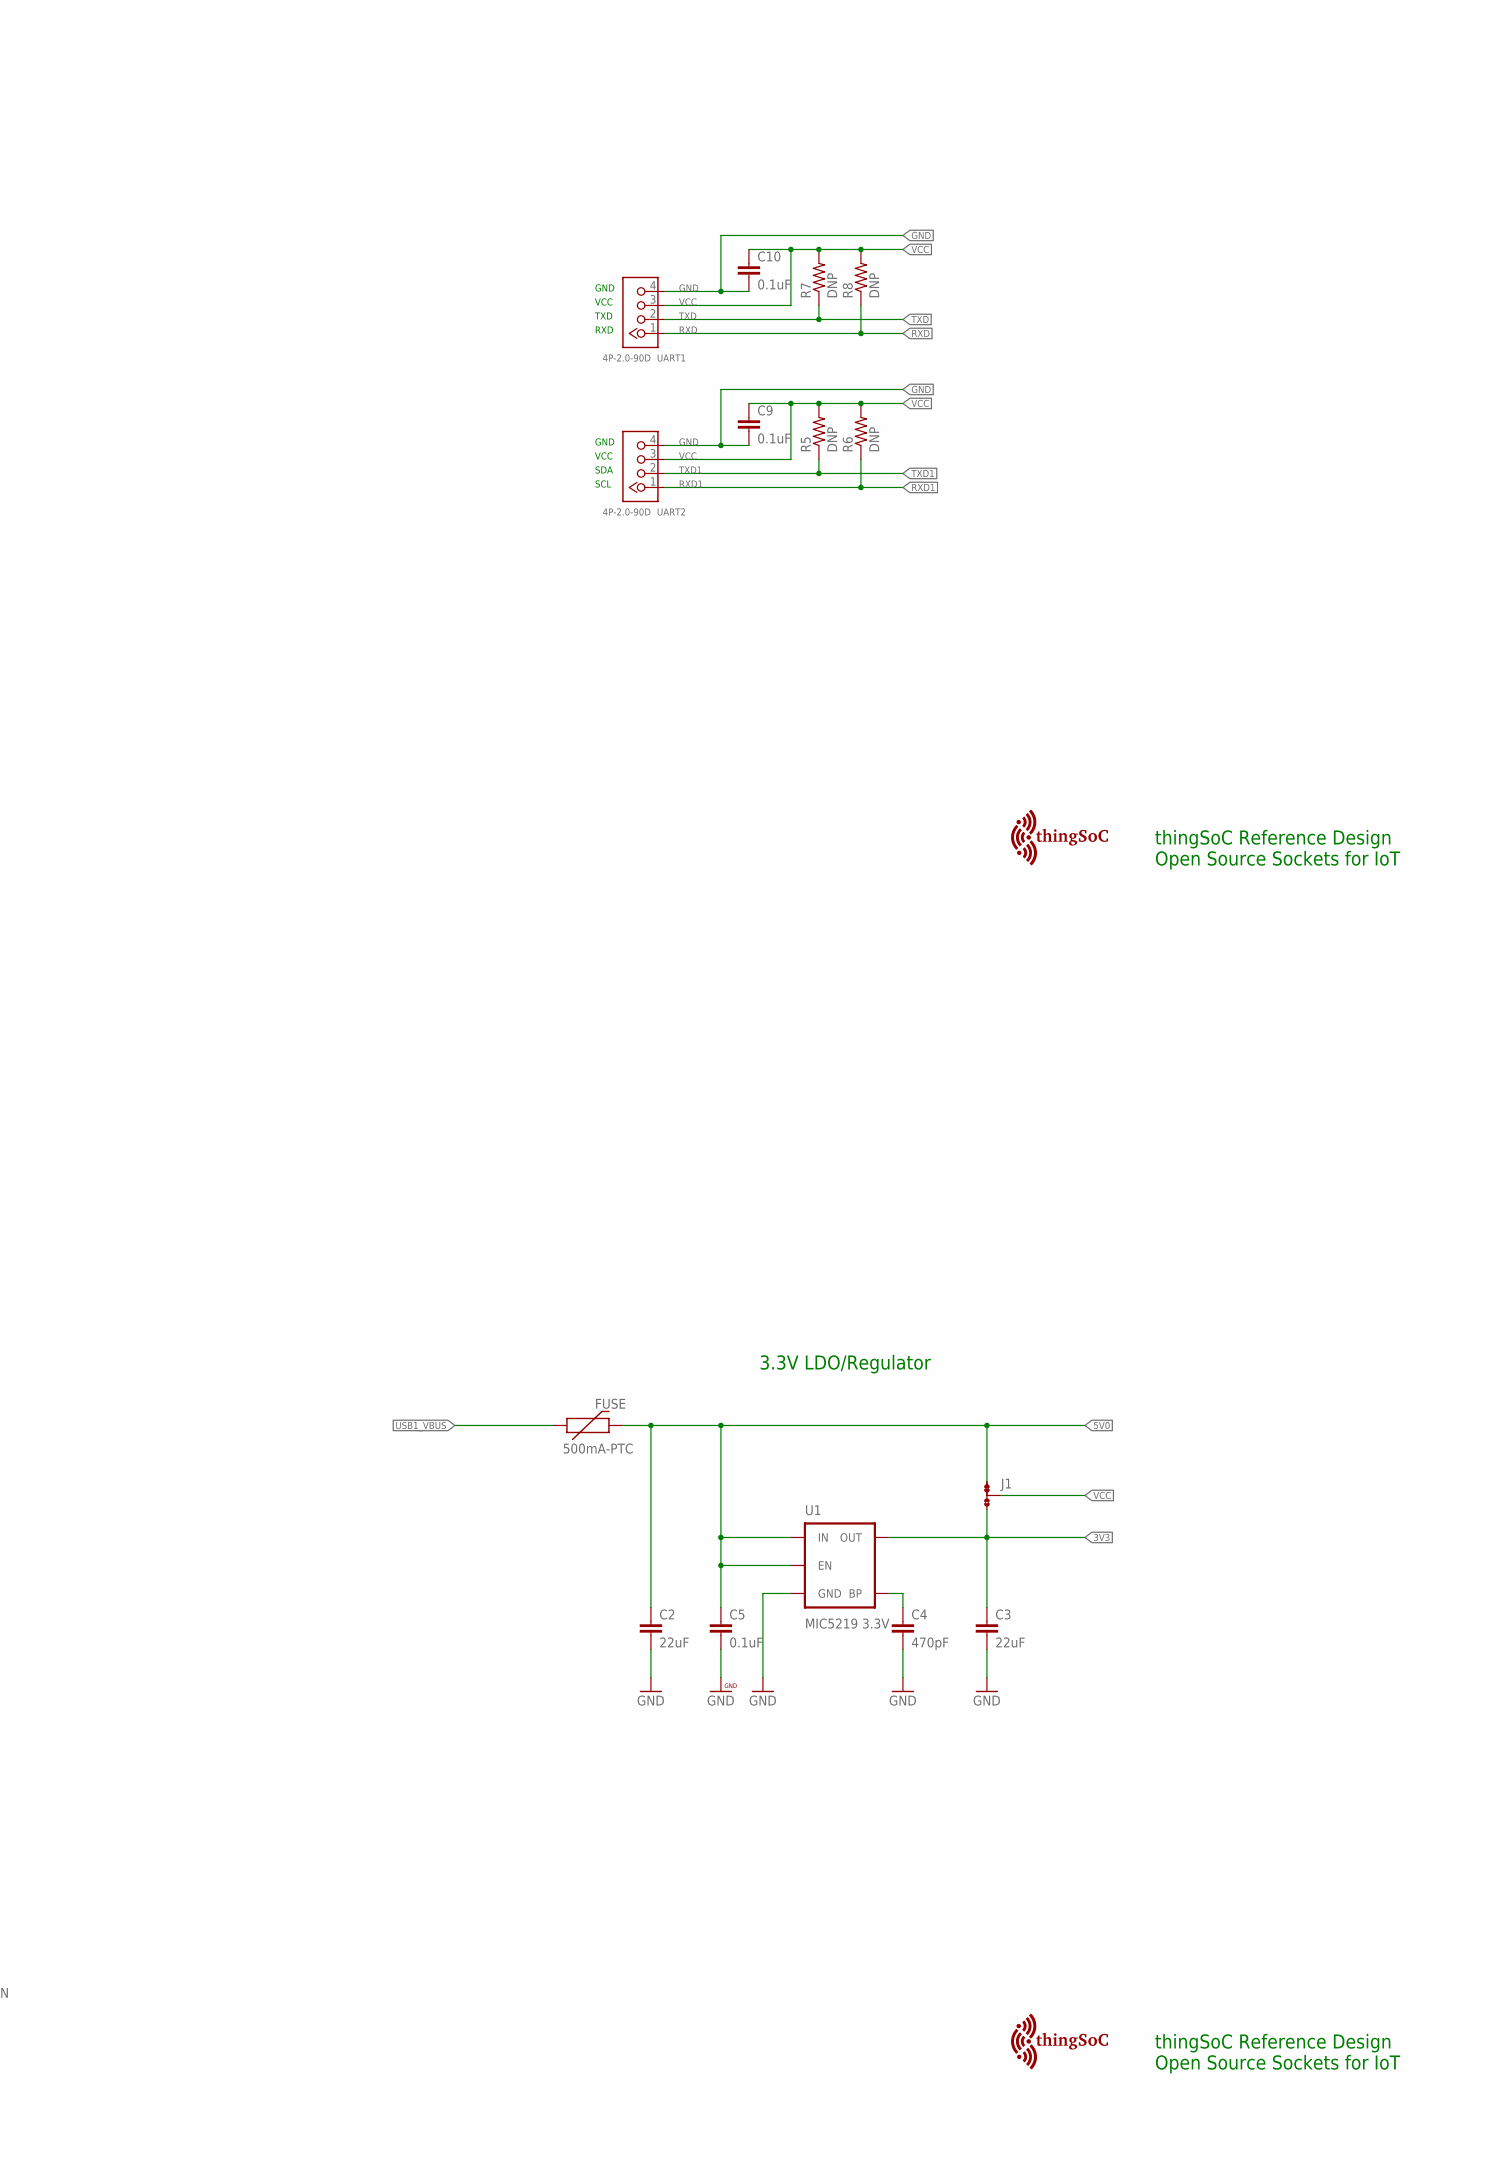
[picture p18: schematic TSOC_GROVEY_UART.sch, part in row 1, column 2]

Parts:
C1, C4: 470pF; EIA-0603
C2, C3: 22uF; EIA-1206
C5, C7, C8: 0.1uF; EIA-0603
C6: 1.0uF; EIA-0603
C9, C10: 0.1uF; 0603-CAP
ESD: SP1001-02JTG; SC70-3
FID1, FID2, FID3, FID4: FIDUCIALUFIDUCIAL; MICRO-FIDUCIAL
FUSE: 500mA-PTC; PTC-1206
J1, J2: JMP-3-1_2
PCB: TSOC-PCB-PLUSMIN; TSOC-BB-BRD-PLUS-MIN-DIM
PORT1: YELLOW; LED-0603
PORT2: BLUE; LED-0603
POWER: GRN; LED-0603
R1: 1M; EIA-0603
R2, R3: 22; EIA-0603
R4, R10, R11, R12: 1K; EIA-0603
R5, R6, R7, R8: DNP; 0603-RES
R13: 22K; EIA-0603
R15, R17: 10K; EIA-0603
SCL: JMP-2-NO
SDA: JMP-2-NO
SUSPEND: RED; LED-0603
TSOC: TSOC-24-BB; TSOC-BB-S24
U1: MIC5219 3.3V; SOT23-5
U2: CY7C65215-32-PROTO; QFN32-PROTO
U$3: TSOC-LOGO-LRG
U$4, U$5, U$6: TSOC-LOGO; TSOC-LOGO-BLANK
UART1, UART2: 4P-2.0-90D; HW4-2.0-90D
USB: USB_AB; USB-AB-MICRO-SMD

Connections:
3V3: C3.1, J1.3, TSOC.11B (3V3), U1.5 (OUT)
5V0: C2.1, C5.1, FUSE.2, J1.1, R13.1, TSOC.11C (5V0), U1.1 (IN), U1.3 (EN), U2.19 (VBUS)
!CTS: TSOC.6C (!CTS), U2.29 (GPIO4)
!CTS1: U2.8 (GPIO13)
!DCD: SUSPEND.C, TSOC.2C (!DCD), U2.11 (SUSPEND)
!DSR: TSOC.3C (!DSR), U2.27 (GPIO2)
!DSR1: U2.9 (GPIO14)
!DTR: TSOC.4C (!DTR), U2.3 (GPIO9)
!DTR1: U2.10 (GPIO15)
!POWER: J2.3, U2.31 (GPIO6)
!RI: TSOC.1C (!RI), U2.12 (WAKEUP)
!RTS: TSOC.5C (!RTS), U2.28 (GPIO3)
!RTS1: U2.7 (GPIO12)
!RX_LED: PORT1.C, U2.26 (GPIO1)
!TX_LED: PORT2.C, U2.25 (GPIO0)
!USB_RST: R17.2, U2.18 (!XRES)
BCD0: U2.22 (GPIO18)
BCD1: U2.21 (GPIO17)
BLU: PORT2.A, R11.1
BUS_DET: R13.2, R15.1, U2.32 (GPIO7)
BYPASS1: C4.1, U1.4 (BP)
GND: C1.2, C2.2, C3.2, C4.2, C5.2, C6.1, C7.1, C8.1, C9.2, C10.2, ESD.3 (A), J2.1, R1.2, R15.2, TSOC.12B (GND), TSOC.12C (AGND), U1.2 (GND), U2.4 (VSSD), U2.17 (VSSD), U2.20 (VSSD), U2.24 (VSSA), U2.EXP (VSSD), UART1.4, UART2.4, USB.GND
GRN: POWER.A, R10.1
PWR: J2.2, POWER.C
RED: R4.1, SUSPEND.A
RXD: R8.1, TSOC.7C (RXD), U2.2 (GPIO8), UART1.1
RXD1: R6.1, SCL.1, U2.5 (GPIO10), UART2.1
SCL: SCL.2, TSOC.9C (SCL)
SDA: SDA.2, TSOC.10C (SDA)
TXD: R7.1, TSOC.8C (TXD), U2.30 (GPIO5), UART1.2
TXD1: R5.1, SDA.1, U2.6 (GPIO11), UART2.2
TXDEN: U2.13 (GPIO16)
USB1_DM: ESD.2 (C2), R3.1, USB.D-
USB1_DP: ESD.1 (C1), R2.1, USB.D+
USB1_ID: USB.ID (USBID)
USB1_M: R3.2, U2.15 (USBDM)
USB1_P: R2.2, U2.14 (USBDP)
USB1_SHIELD: C1.1, R1.1, USB.SHIELD1, USB.SHIELD2
USB1_VBUS: FUSE.1, USB.VBUS
VCC: C7.2, C8.2, C9.1, C10.1, J1.2, R4.2, R5.2, R6.2, R7.2, R8.2, R10.2, R11.2, R12.2, R17.1, U2.1 (VDDD), U2.23 (VDDD), UART1.3, UART2.3
VCCD1: C6.2, U2.16 (VCCD)
YEL: PORT1.A, R12.1

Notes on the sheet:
thingSoC Reference Design Open Source Sockets for IoT
USB "B"
Device
thingSoC Grovey UART Reference Design Page A : thingSoC IoT Socket Page B : 3.3 Volt Power Supply Page C : Dual USB to UART Bridge Device Page D : Grove System Output Connectors
DUAL USB to UART Interface
thingSoC Module Template
3.3V LDO/Regulator
GND
VCC
RXD
TXD
SDA
SCL

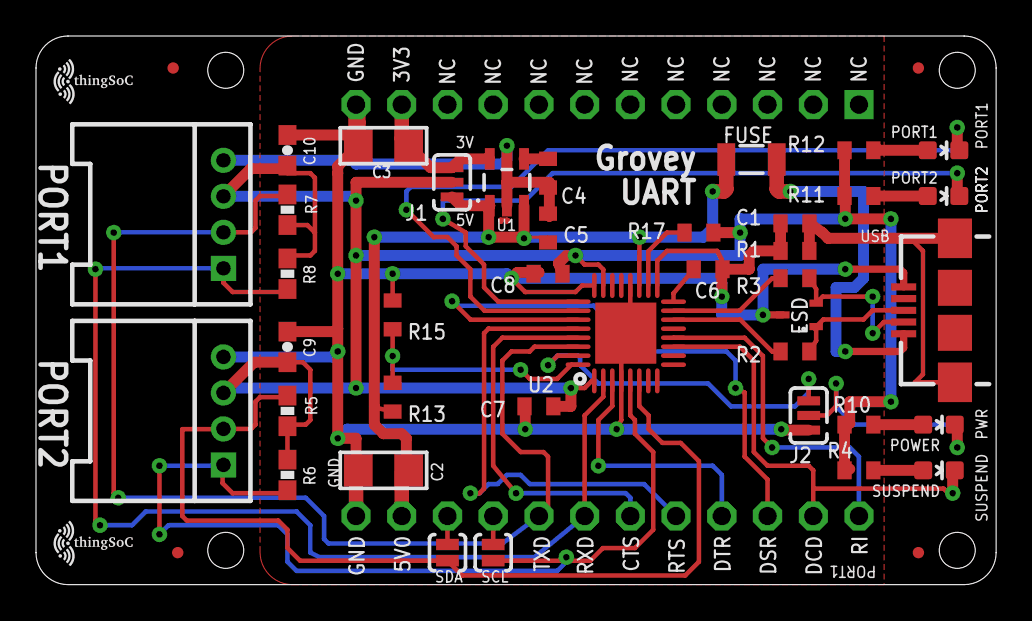
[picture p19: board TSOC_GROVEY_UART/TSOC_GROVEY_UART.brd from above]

Board: 2 copper layers, 53.3 x 30.5 mm, 51 parts (1 on the bottom side), 34 nets.

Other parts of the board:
U$1, U$7: TSOC-LOGO-SMALL; TSOC-LOGO-SML

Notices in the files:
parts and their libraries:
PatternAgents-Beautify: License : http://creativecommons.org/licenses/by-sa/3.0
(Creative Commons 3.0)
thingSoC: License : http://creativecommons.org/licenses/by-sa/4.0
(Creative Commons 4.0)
